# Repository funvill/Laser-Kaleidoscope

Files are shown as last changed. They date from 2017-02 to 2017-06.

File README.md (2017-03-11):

# Laser Kaleidoscope

A circular light box that incorporates moving lasers which generate twisting fractal shapes. 16 servos are evenly placed around the circle. Each servo has a laser diode on it, with a vertical fresnel len creating a line. The servos will rotate creating patterns inspired by mathematical formulas, cardioids and fractals. This project is based on this video [Times Tables, Mandelbrot and the Heart of Mathematics](https://www.youtube.com/watch?v=qhbuKbxJsk8) by Burkard Polster also known as [Mathologer](https://www.youtube.com/channel/UC1_uAIS3r8Vu6JjXWvastJg). An interactive animation of these fractals can be found here http://entibo.fr/timesTables/

More [information, photos and videos](https://blog.abluestar.com/projects/2017-laser-kaleidoscope) can be found on my blog. 

Laser Kaleidoscope (https://www.youtube.com/watch?v=XHqZNfPvEVY)

# Wiring
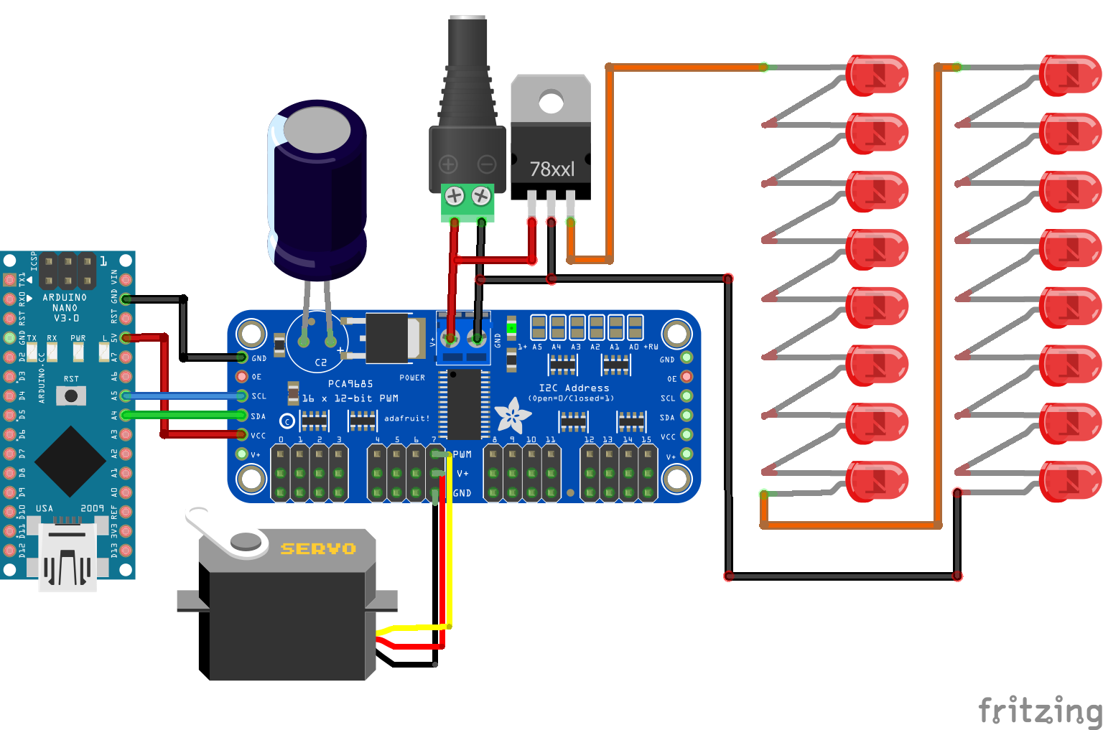
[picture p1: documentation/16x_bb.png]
Wiring


# Parts

- [Adafruit 16-channel PWM & Servo driver](http://www.adafruit.com/products/815)
- 16x [9g servo motors](https://www.aliexpress.com/item/Free-Shipping-5PCS-LOT-SG90-9g-Mini-Micro-Servo-for-RC-for-RC-250-450-Helicopter/32349297925.html)
- 16x [line laser pointers](https://www.aliexpress.com/item/Free-shipping-10pcs-lot-9MM-laser-head-laser-tube-laser-diode-3V-30ma-5mw-red-dot/32457307836.html) 
- [Pololu 3.3V Step-Up/Step-Down Voltage Regulator S7V8F3](https://www.pololu.com/product/2122)
- [Mean Well DR-4505](http://ca.mouser.com/ProductDetail/Mean-Well/DR-4505/) - DIN Rail Power Supplies 25W 5V 5A
- [DC Power Jack Barrel Plug Connector 2.1 Terminal](https://www.aliexpress.com/item/Freeshipping-new-DC-Power-Female-Jack-Barrel-Plug-Connector-2-1-x-5-5-mm-Adapter/32795063393.html)

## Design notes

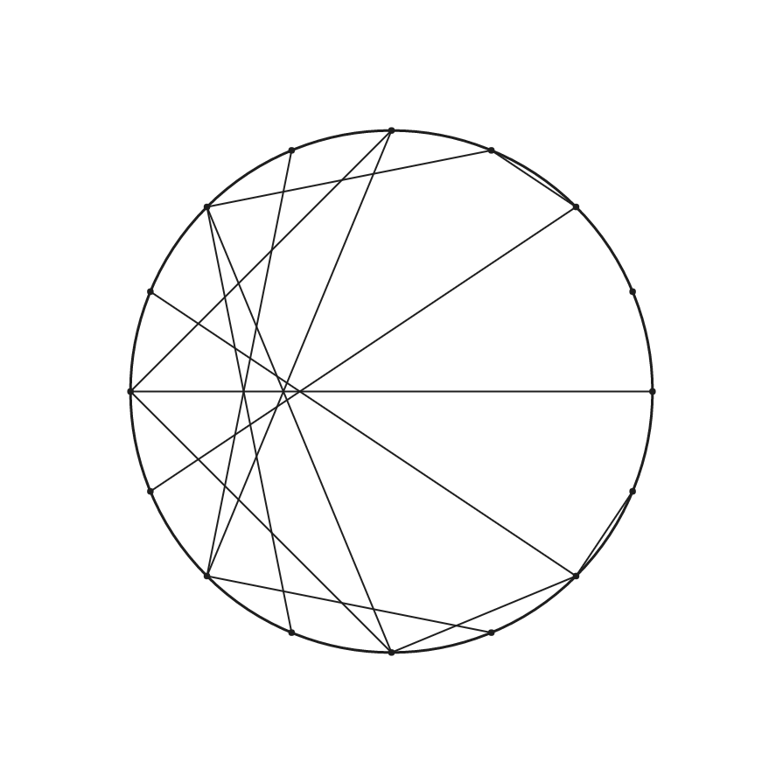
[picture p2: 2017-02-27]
documentation/16x_table2.png

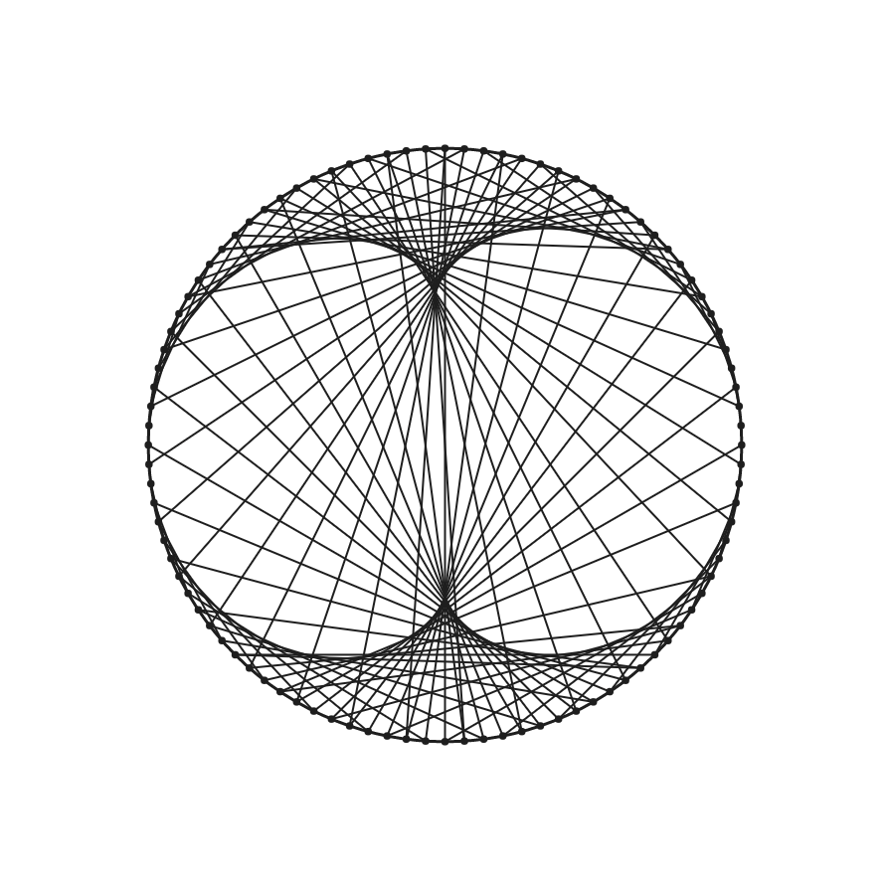
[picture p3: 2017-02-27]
documentation/96x_table3.png

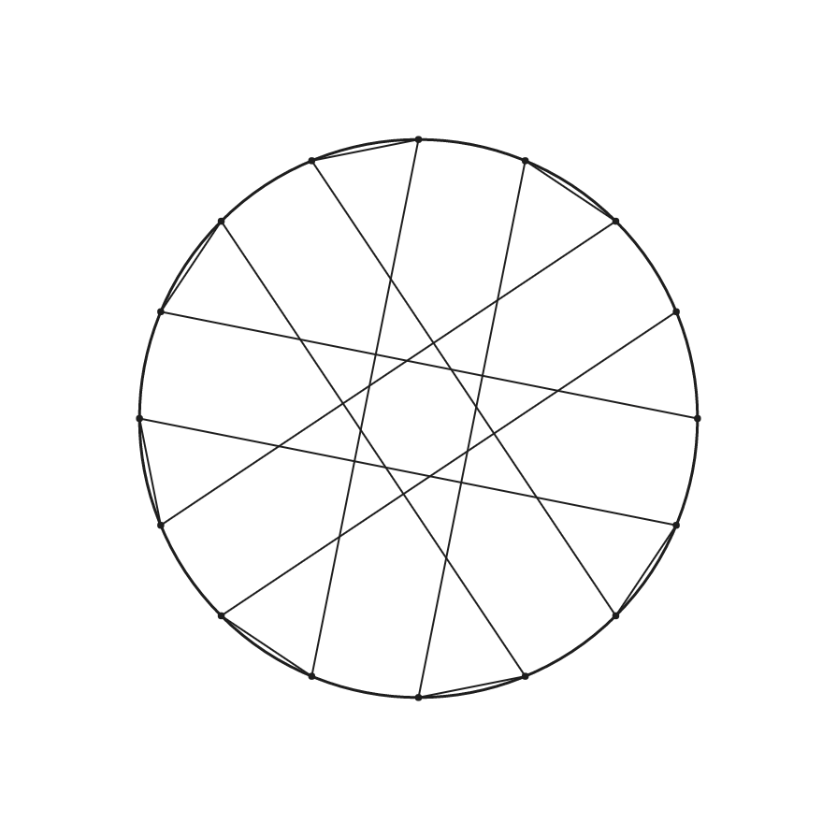
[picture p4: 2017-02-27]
documentation/16x_table9.png

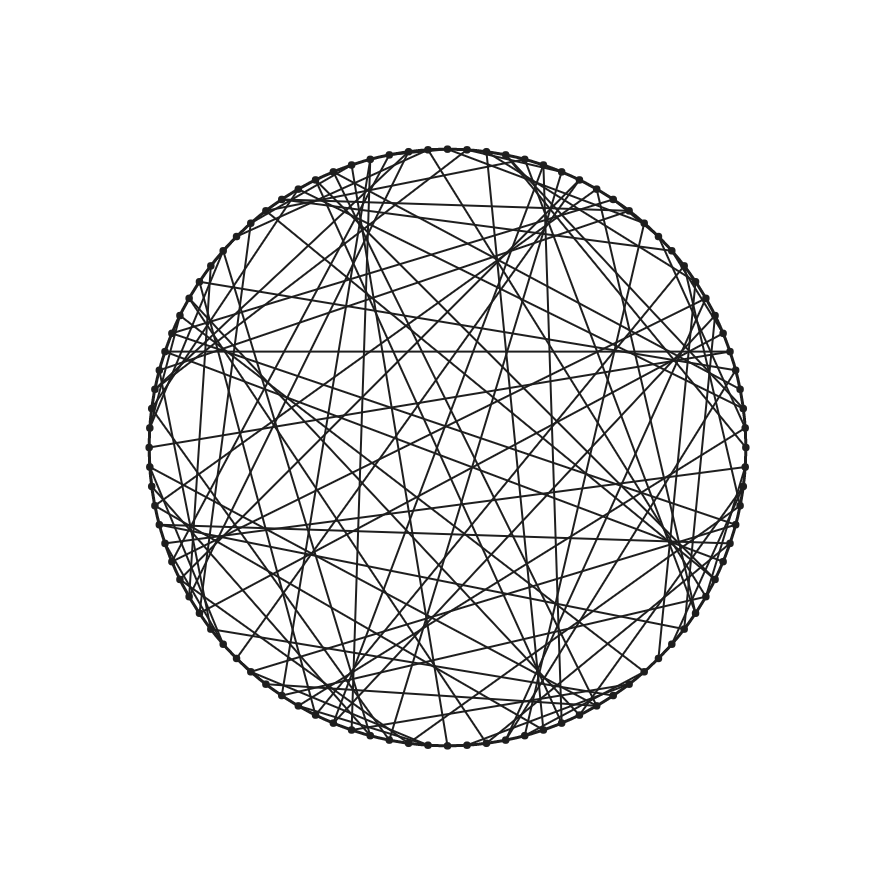
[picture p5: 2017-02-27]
documentation/96x_table9.png

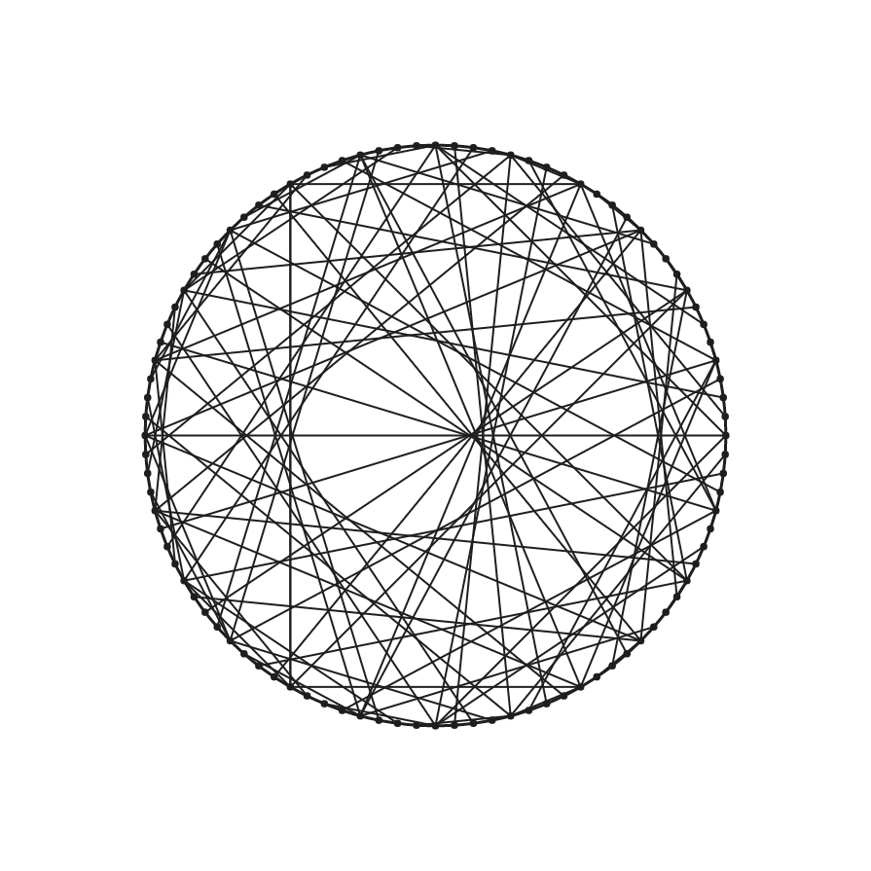
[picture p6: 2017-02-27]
documentation/96x_table20.png

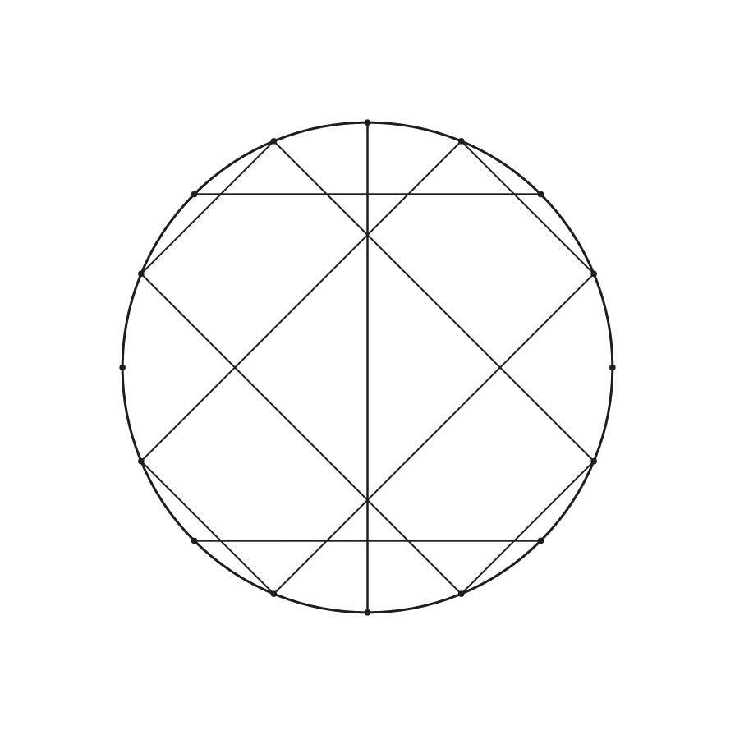
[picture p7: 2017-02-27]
documentation/16x_table3.png

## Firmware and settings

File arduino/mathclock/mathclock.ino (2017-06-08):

/****************************************************************************** 

  Math clock 
  =============================================================================
  Last updated: 2017-Feb-26
  Created by: Steven Smethurst @funvill 

  More information can be found here 
  https://github.com/funvill/mathclock

  Hardware
  -----------------------------------------------------------------------------
  - Adafruit 16-channel PWM & Servo driver http://www.adafruit.com/products/815
  - 16 9g servo motors 
  - 16 line laser pointers. 

  Libaries 
  -----------------------------------------------------------------------------
  - Adafruit-PWM-Servo-Driver-Library https://github.com/adafruit/Adafruit-PWM-Servo-Driver-Library 

  Pin out
  -----------------------------------------------------------------------------
  Arduino Nano      PCA9685 (Adafruit 16-channel PWM & Servo driver) 
  GND           ==> GND 
  Not connected ==> DE 
  A5            ==> SCL
  A4            ==> SDA    
  5V            ==> VCC 
  5V            ==> V+

******************************************************************************/

#include <Wire.h>
#include <Adafruit_PWMServoDriver.h>

// Consts
// ============================================================================
static const char *SKETCH_VERSION = "0.4";
static const char *SKETCH_LAST_UPDATED = "2017-Mar-10";

// Servo Consts
// ----------------------------------------------------------------------------
// Depending on your servo make, the pulse width min and max may vary, you
// want these to be as small/large as possible without hitting the hard stop
// for max range. You'll have to tweak them as necessary to match the servos you
// have!

// The servo starts at 130, but we want to limit the range at 160 to be inline with the first
// servo in the series.
static const unsigned short SETTING_SERVOMIN = 160;

// The servo stops at 600, but we want to limit the range at 500 to be inline with the last
// servo in the series.
static const unsigned short SETTING_SERVOMAX = 500;

// Analog servos run at ~60 Hz updates
static const unsigned short SETTING_PWM_FREQUENCY = 60;

// Settings
// ============================================================================
static const unsigned short SETTING_MAX_NODES = 16;
static const unsigned short SETTING_FRAME_DELAY = 1000 * 5;
static const float SETTING_MOVEMENT_RATE = 0.5f;

// All the servos are off by a little bit. This is the difference that they are off by.
static short SERVO_CALABRATION[SETTING_MAX_NODES];

// Globals
// ============================================================================
unsigned char gPattern;

// called this way, it uses the default address 0x40
// Adafruit_PWMServoDriver pwm = Adafruit_PWMServoDriver( 0x40);
Adafruit_PWMServoDriver gServoDriver = Adafruit_PWMServoDriver();

// Utility functions
// ---------------------------------------------
// This function saves the servo from wear and tear. It turns off the power to the
// servo.
void TurnOffServos(unsigned short delayAfter, unsigned short delayBefore = 50)
{
  Serial.println("TurnOffServos delayAfter= " + String(delayAfter) + ", delayBefore= " + String(delayBefore));
  if (delayBefore > 0)
  {
    delay(delayBefore);
  }
  /*
  // This is not working, Crashes the Arduino. 
  for (unsigned char node = 0; node <= SETTING_MAX_NODES; node++) {
    gServoDriver.setPWM(node, 4096, 0);
  }
  */

  delay(delayAfter);
}

void SetServoDegrees(unsigned char node, float deg)
{
  unsigned char nodeMod = node % SETTING_MAX_NODES;
  Serial.println("SetServoDegrees node= " + String(nodeMod) + ", deg= " + String(deg));

  // Add SERVO_CALABRATION offsets
  if (deg + SERVO_CALABRATION[nodeMod] > 180)
  {
    deg = 180;
  }
  else if (deg + SERVO_CALABRATION[nodeMod] < 0)
  {
    deg = 0;
  }
  else
  {
    deg += SERVO_CALABRATION[nodeMod];
  }

  // Convert deg to pulselen
  int pulselen = map(deg, 0, 180, SETTING_SERVOMIN, SETTING_SERVOMAX);
  gServoDriver.setPWM(nodeMod, 0, pulselen);
}

float PointAtAbsolute(unsigned char node, float target)
{
  Serial.println("PointAtAbsolute node= " + String(node) + ", target= " + String(target));
  float degrees = PointAtDelta(FindDeltaNode(node, target));
  Serial.println("\tPointAtAbsolute.Degrees= " + String(degrees));
  return degrees;
}

float PointAtDelta(float deltaPoint)
{
  Serial.println("PointAtDelta deltaPoint= " + String(deltaPoint) + ", nodeCount= " + String(SETTING_MAX_NODES));

  // I don't understand any of this. This was made by @Luthor2k https://github.com/Luthor2k
  // It finds the angle between to points on a circle. Basic grade 11 math. It works!
  float beta = deltaPoint * ((2 * PI) / SETTING_MAX_NODES);
  float rho = atan(sin(beta) / (1 - cos(beta)));
  float theta = (PI / 2) - rho;
  float thetaDegrees = (theta / PI) * 180;

  Serial.println("\tPointAtDelta.thetaDegrees= " + String(thetaDegrees));
  return thetaDegrees;
}

void CreateServoCalabrationTable()
{
  // This table is manually generated.
  // The teeth of the serovs do not let all of the lasers to be places in perfect order.
  // I used the LasersToCenter() function then check to see how far each laser was off from
  // pointing at the laser directly across from them. Then I made a guess and updated this table.
  SERVO_CALABRATION[0] = 8;
  SERVO_CALABRATION[1] = -8;
  SERVO_CALABRATION[2] = -8;
  SERVO_CALABRATION[3] = -5;
  SERVO_CALABRATION[4] = -3;
  SERVO_CALABRATION[5] = 5;
  SERVO_CALABRATION[6] = -7;
  SERVO_CALABRATION[7] = -15 ; // -5;
  SERVO_CALABRATION[8] = 8;
  SERVO_CALABRATION[9] = -2;
  SERVO_CALABRATION[10] = 10;
  SERVO_CALABRATION[11] = -3;
  SERVO_CALABRATION[12] = 7;
  SERVO_CALABRATION[13] = 0;
  SERVO_CALABRATION[14] = -7;
  SERVO_CALABRATION[15] = 7;
}

float FindDeltaNode(unsigned char node, float target)
{
  Serial.println("FindDeltaNode node= " + String(node) + ", target= " + String(target));

  unsigned char nodeMod = node % SETTING_MAX_NODES;
  float targetMod = fmod(target, SETTING_MAX_NODES);

  float deltaPoint = nodeMod - targetMod;
  if (deltaPoint < 0.0f)
  {
    deltaPoint = SETTING_MAX_NODES + (nodeMod - targetMod);
  }

  if (deltaPoint == 0)
  {
    // Don't move.
    return SETTING_MAX_NODES / 2;
  }

  Serial.println("\tFindDeltaNode.deltaPoint= " + String(deltaPoint));
  return deltaPoint;
}

void FindServoMinAndMax()
{
  unsigned char node = 0;
  int pulselen = 0;
  Serial.println("CalibrateServo\n=========================");
  Serial.println("SERVOMIN: " + String(SETTING_SERVOMIN) + ", SERVOMAX: " + String(SETTING_SERVOMAX) + ", PWM Freq: " + String(SETTING_PWM_FREQUENCY));

  // Find the min and max pulselen of a servo.
  // Instructions:
  // 1. Set the SERVOMIN = 0, and SERVOMAX = 4096.
  // 2. Let the following sequence run, recored when the servo starts moving (min), and when it stops moving (max)
  // 3. Update SERVOMIN and SERVOMAX to match.
  Serial.println("Detect the SERVOMIN and SERVOMAX");
  Serial.println("pulselen, degrees");
  for (unsigned short pulselen = SETTING_SERVOMIN; pulselen < SETTING_SERVOMAX; pulselen += 10)
  {
    gServoDriver.setPWM(node, 0, pulselen);

    unsigned short degrees = map(pulselen, SETTING_SERVOMIN, SETTING_SERVOMAX, 0, 180);
    Serial.println(String(pulselen) + ",\t   " + String(degrees));
    TurnOffServos(500);
  }

  return;
}

// Pattern functions
// ---------------------------------------------
void LasersToCenter()
{
  int pulselen = 0;
  for (unsigned char node = 0; node <= SETTING_MAX_NODES; node++)
  {
    SetServoDegrees(node, 90);
  }
  TurnOffServos(SETTING_FRAME_DELAY);
}

void FullScan()
{
  Serial.println("FullScan\n-----------------------------------------");
  unsigned char scanRate = 1;
  unsigned short moveDelay = 1;

  // All servos, full scan
  Serial.println("All servos full scan");

  // Forwards.
  for (short degrees = 0; degrees <= 180; degrees += scanRate)
  {
    for (unsigned char node = 0; node <= SETTING_MAX_NODES; node++)
    {
      SetServoDegrees(node, degrees);
    }
    delay(moveDelay);
  }

  // Backwards
  for (short degrees = 180; degrees > 0; degrees -= scanRate)
  {
    for (unsigned char node = 0; node <= SETTING_MAX_NODES; node++)
    {
      SetServoDegrees(node, degrees);
    }
    delay(moveDelay);
  }
}

void AllLasersPointAtDeltaSameTarget()
{
  Serial.println("AllLasersPointAtDeltaSameTarget\n-----------------------------------------");
  for (unsigned short target = 0; target <= SETTING_MAX_NODES; target++)
  {
    for (unsigned char node = 0; node <= SETTING_MAX_NODES; node++)
    {
      float deltaPoint = FindDeltaNode(node, target);
      float degrees = PointAtDelta(deltaPoint);
      SetServoDegrees(node, degrees);
    }
    TurnOffServos(SETTING_FRAME_DELAY);
  }
}

void LasersToStartingLocations()
{
  Serial.println("LasersToStartingLocations\n-----------------------------------------");
  int pulselen = 0;
  for (unsigned char node = 0; node <= SETTING_MAX_NODES; node++)
  {
    float degrees = PointAtDelta(1);
    SetServoDegrees(node, degrees);
  }
  TurnOffServos(SETTING_FRAME_DELAY);
}

void TimesTables()
{
  Serial.println("TimesTables\n-----------------------------------------");
  for (float timesTable = 1.0f; timesTable < SETTING_MAX_NODES; timesTable += SETTING_MOVEMENT_RATE)
  {
    Serial.println("TimesTable=" + String(timesTable));

    for (unsigned char node = 0; node <= SETTING_MAX_NODES; node++)
    {
      float target = node * timesTable;
      float deltaPoint = FindDeltaNode(node, target);

      float degrees = PointAtDelta(deltaPoint);
      SetServoDegrees(node, degrees);
    }
    TurnOffServos(SETTING_FRAME_DELAY);
  }
}

void FuckingRandom()
{
  Serial.println("FuckingRandom\n-----------------------------------------");
  LasersToCenter();
  TurnOffServos(SETTING_FRAME_DELAY);

  for (unsigned char node = 0; node <= SETTING_MAX_NODES; node++)
  {
    SetServoDegrees(node, random(30, 180 - 30));
  }
  TurnOffServos(SETTING_FRAME_DELAY);
}

void SquareBoxesCycling()
{
  Serial.println("SquareBoxesCycling\n-----------------------------------------");
  for (float offset = 0; offset < SETTING_MAX_NODES; offset += 0.2f)
  {
    SetServoDegrees(0, PointAtAbsolute(0, 5 + offset));
    SetServoDegrees(5, PointAtAbsolute(5, 0 + offset));

    SetServoDegrees(8, PointAtAbsolute(8, 13 + offset));
    SetServoDegrees(13, PointAtAbsolute(13, 8 + offset));

    SetServoDegrees(1, PointAtAbsolute(1, 12 + offset));
    SetServoDegrees(12, PointAtAbsolute(12, 1 + offset));

    SetServoDegrees(4, PointAtAbsolute(4, 9 + offset));
    SetServoDegrees(9, PointAtAbsolute(9, 4 + offset));

    // Set everything else to zero
    // Do this only once
    if (offset == 0.0f)
    {
      SetServoDegrees(11, 0);
      SetServoDegrees(14, 0);
      SetServoDegrees(3, 0);
      SetServoDegrees(6, 0);

      SetServoDegrees(2, 0);
      SetServoDegrees(7, 0);
      SetServoDegrees(10, 0);
      SetServoDegrees(15, 0);
    }
    delay(10);
  }
}
void NicePatterns()
{
  Serial.println("NicePatterns\n-----------------------------------------");
  unsigned char nicePatterOffset = 0;
  while (true)
  {
    switch (nicePatterOffset)
    {
    // Times tables= 2
    case 0:
      for (unsigned char node = 0; node <= SETTING_MAX_NODES; node++)
      {
        SetServoDegrees(node, PointAtDelta(FindDeltaNode(node, node * 2)));
      }
      break;

    // Times tables= 14
    case 1:
      for (unsigned char node = 0; node <= SETTING_MAX_NODES; node++)
      {
        SetServoDegrees(node, PointAtDelta(FindDeltaNode(node, node * 14)));
      }
      break;

    // Times tables= 16
    case 2:
      for (unsigned char node = 0; node <= SETTING_MAX_NODES; node++)
      {
        SetServoDegrees(node, PointAtDelta(FindDeltaNode(node, node * 16)));
      }
      break;
    case 3:
      // Pentagram
      for (unsigned char node = 0; node <= SETTING_MAX_NODES; node += 2)
      {
        SetServoDegrees(node, PointAtDelta(FindDeltaNode(node, node + 4)));
      }

      // Off
      for (unsigned char node = 1; node <= SETTING_MAX_NODES; node += 2)
      {
        SetServoDegrees(node, 0);
      }

      break;

    default:
      // Done
      return;
    }
    nicePatterOffset++;
    TurnOffServos(SETTING_FRAME_DELAY);
  }
}

void TwoSideFanRotating()
{
  for (unsigned char offset = 0; offset <= SETTING_MAX_NODES; offset++)
  {
    for (unsigned char node = 0; node <= SETTING_MAX_NODES / 2; node += 1)
    {
      SetServoDegrees(node + offset, PointAtAbsolute(node + offset, 4 + offset));
    }
    for (unsigned char node = SETTING_MAX_NODES / 2; node <= SETTING_MAX_NODES; node += 1)
    {
      SetServoDegrees(node + offset, PointAtAbsolute(node + offset, 12 + offset));
    }
    TurnOffServos(10);
  }
}

void TestPattern()
{
  
  TurnOffServos(SETTING_FRAME_DELAY * 30);
}

void setup()
{
  Serial.begin(115200);
  Serial.println("Version: " + String(SKETCH_VERSION));
  Serial.println("Last updated: " + String(SKETCH_LAST_UPDATED));

  CreateServoCalabrationTable();

  // Start up the servos.
  gServoDriver.begin();
  gServoDriver.setPWMFreq(SETTING_PWM_FREQUENCY);

  // Lasers to starting Locations. Pointing at nearest neighbour
  LasersToStartingLocations();
  LasersToCenter();

  gPattern = 0;
}

void loop()
{
  // LasersToCenter(); 
  // TestPattern() ; 
  // return;

  switch (gPattern++)
  {
  case 0:
    FullScan();
    break;
  case 1:
    AllLasersPointAtDeltaSameTarget();
    break;
  case 2:
    TimesTables();
    break;
  case 3:
  case 4:
  case 5:
    SquareBoxesCycling();
    break;
  case 6:
    NicePatterns();
    break;
  case 7:
    TwoSideFanRotating();
    break;

  default:
    gPattern = 0;
    break;
  }

  return;
}

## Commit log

2017-02-26 excel doc with circle/angle calc
    [circle_calculator.ods]
2017-02-26 Added working version of the mathclock
    [circle_calculator.ods]
2017-02-26 Optimization of Servo angle code.
2017-02-26 Renamed arduino project to mathclock
2017-02-27 Optimization and calibration code
2017-02-27 Added picturs to the readme
    [16x.fzz]
2017-03-10 Added servo calabration to deal with offset servos
2017-03-11 Fixed floating point math problem in FindDeltaNode() function
    [mathclock.ino]
2017-03-11 Updating wiring diagram
    [16x.fzz]
